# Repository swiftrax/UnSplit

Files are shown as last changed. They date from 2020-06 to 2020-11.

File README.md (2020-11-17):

# UnSplit
A Kyria layout with some of the thumb keys removed. It is non split and powered by an ATMega32u4-AU. Featuring an exposed component layout with diodes in a bank.

## PCB Renders
Top Full Ground Plane
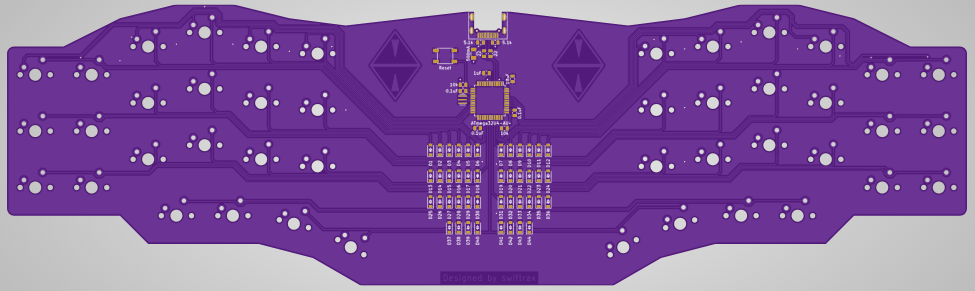
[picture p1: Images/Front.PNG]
Front Full Ground Plane

Bottom Full Ground Plane
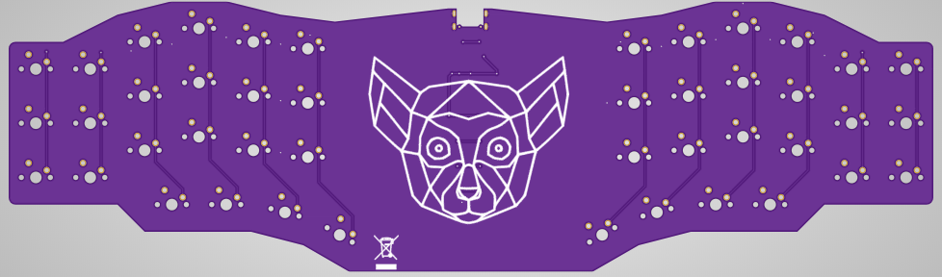
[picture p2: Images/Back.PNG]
Back Full Ground Plane

Top Partial Ground Plane
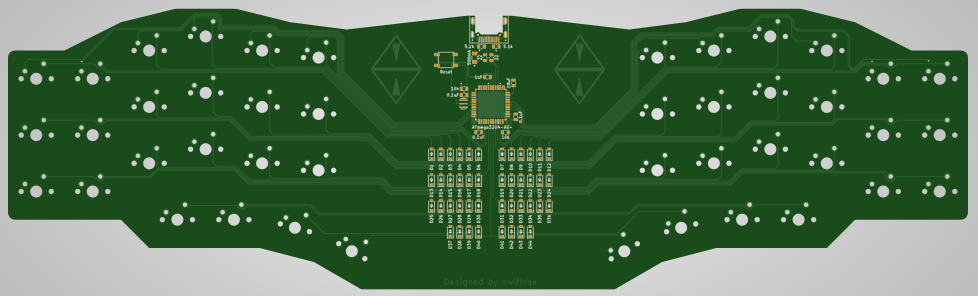
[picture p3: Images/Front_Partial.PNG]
Front Partial Ground Plane

Bottom Partial Ground Plane
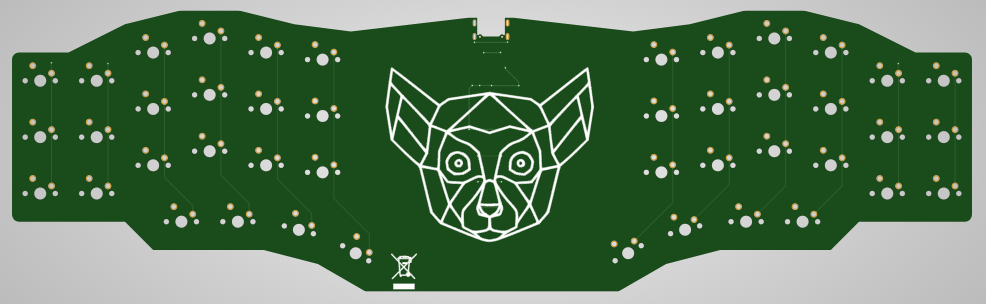
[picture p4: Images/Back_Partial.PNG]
Back Partial Ground Plane

*Open with KiCad nightly*

## Bill of Materials
* [ATMega32u4-AU x 1](https://lcsc.com/product-detail/ATMEL-AVR_Microchip-Tech-ATMEGA32U4-AU_C44854.html)
* [16MHz Resonator x 1](https://lcsc.com/product-detail/Others_Murata-Electronics-CSTNE16M0V530000R0_C341521.html)
* [22 Ohm Resistor x 2](https://lcsc.com/product-detail/Chip-Resistor-Surface-Mount_TyoHM-RMC0805221-N_C325772.html)
* [5.1k Ohm Resistor x 2](https://lcsc.com/product-detail/Chip-Resistor-Surface-Mount_TyoHM-RMC08055-1K1-N_C269748.html)
* [10k Ohm Resistor x 2](https://lcsc.com/product-detail/Chip-Resistor-Surface-Mount_TyoHM-RMC080510K1-N_C269742.html)
* [100nF Capactior x 3](https://lcsc.com/product-detail/Multilayer-Ceramic-Capacitors-MLCC-SMD-SMT_Walsin-Tech-Corp-0805B104J500CT_C314285.html)
* [1uF Capactior x 1](https://lcsc.com/product-detail/Multilayer-Ceramic-Capacitors-MLCC-SMD-SMT_FH-Guangdong-Fenghua-Advanced-Tech-0805B105K500NT_C215803.html)
* [10uF Capactior x 1](https://lcsc.com/product-detail/Multilayer-Ceramic-Capacitors-MLCC-SMD-SMT_SAMSUNG_CL10A106MA8NRNC_10uF-106-20-25V_C96446.html)
* [500mA Polyfuse x 1](https://lcsc.com/product-detail/Surface-Mount-Fuses_0-25A-16V-Self-healing-fuse_C70068.html)
* [Reset Switch x 1](https://lcsc.com/product-detail/Tactile-Switches_C-K_RS-187R05A2-DSMTRT_C-K-RS-187R05A2-DSMTRT_C221929.html)
* [Type C Port x 1](https://lcsc.com/product-detail/USB-Type-C_Korean-Hroparts-Elec-TYPE-C-31-M-14_C223907.html)
* [Diodes x 44](https://lcsc.com/product-detail/Diodes-General-Purpose_MDD-Microdiode-Electronics-SM4007PL_C64898.html)

*Capactiors and Resistors are 0805 Package size*

## License

This repository is under the [GNU GPL V2 license](https://github.com/swiftrax/UnSplit/blob/master/LICENSE). If you plan to sell these pcbs, make sure to read it.

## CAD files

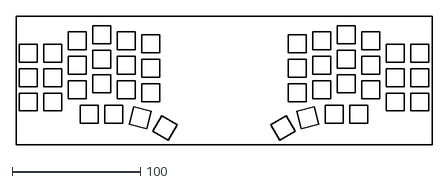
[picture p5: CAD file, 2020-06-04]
Plate/Plate.dxf
323.8 x 99.9

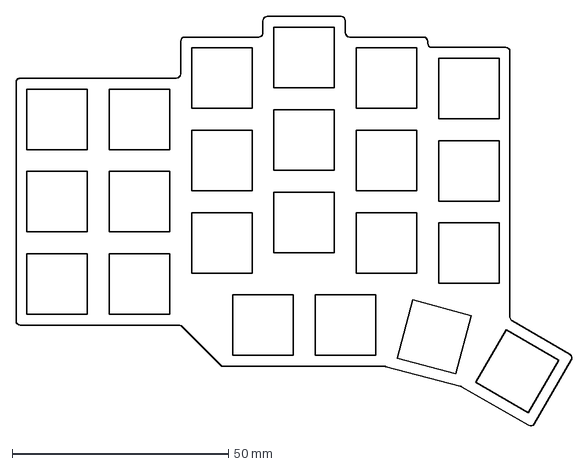
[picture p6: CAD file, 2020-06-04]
Plate/1Plate.dxf
128.6 x 94.9 mm

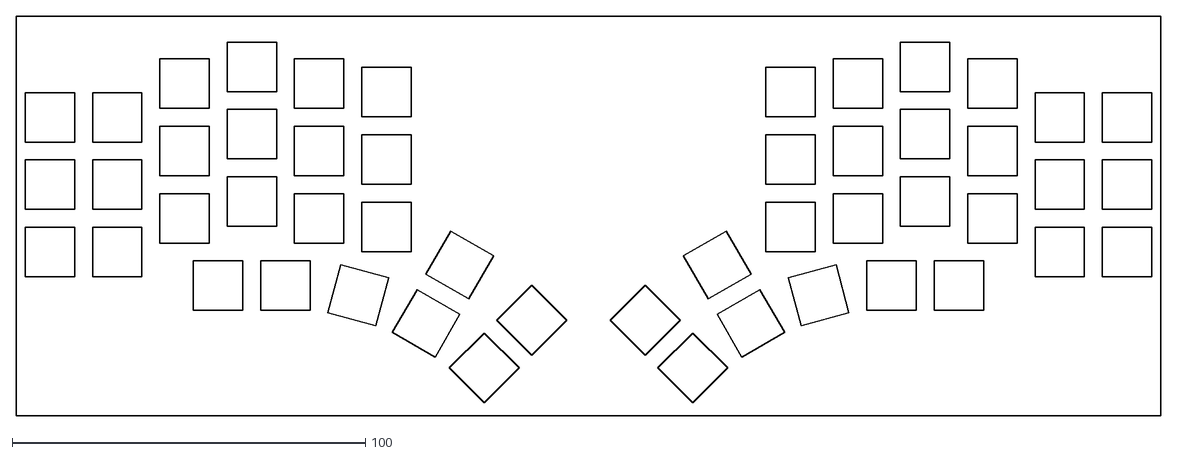
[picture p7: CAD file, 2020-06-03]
Plate/SwitchLayout.dxf
323.8 x 113.0

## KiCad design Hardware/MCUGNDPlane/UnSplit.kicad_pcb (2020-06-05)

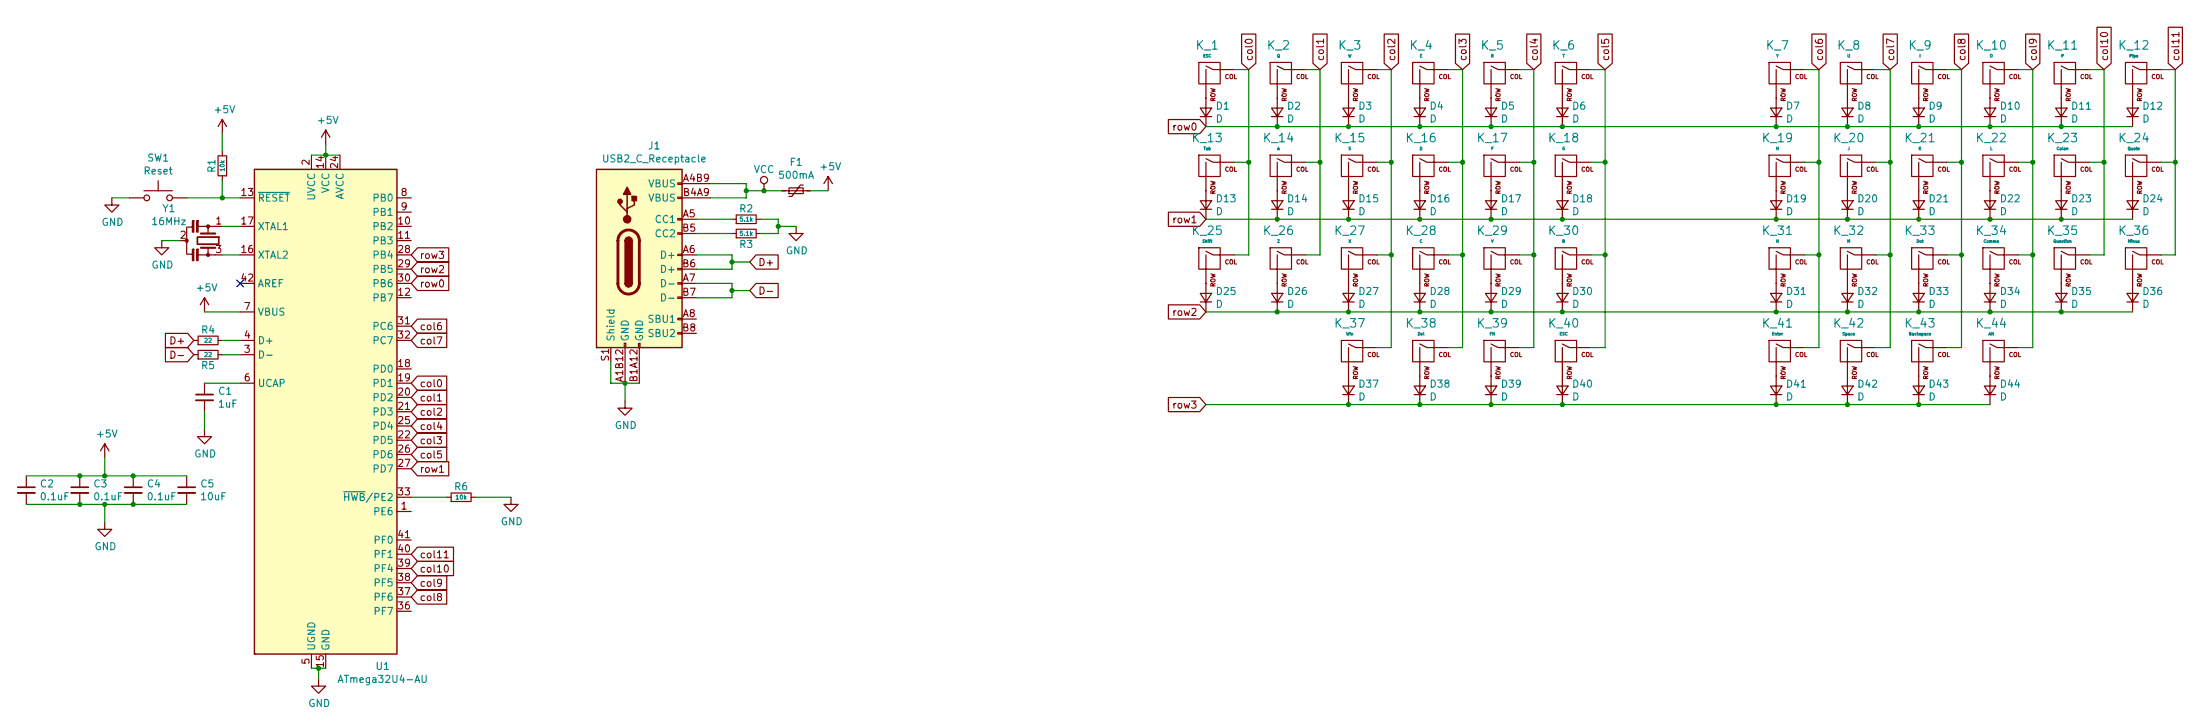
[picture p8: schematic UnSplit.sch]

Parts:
C1: 1uF; C_0805_2012Metric
C2, C3, C4: 0.1uF; C_0805_2012Metric
C5: 10uF; C_0805_2012Metric
D1, D2, D3, D4, D5, D6, D7, D8, D9, D10, D11, D12, D13, D14, D15, D16, D17, D18, D19, D20, D21, D22, D23, D24, D25, D26, D27, D28, D29, D30, D31, D32, D33, D34, D35, D36, D37, D38, D39, D40, D41, D42, D43, D44: D; D_SOD-123
F1: 500mA; Fuse_1206_3216Metric
J1: USB2_C_Receptacle; Mid_Mount-USB_C_HandSoldering
K_1, K_40: ESC; MXOnly-1U-NoLED
K_2: Q; MXOnly-1U-NoLED
K_3: W; MXOnly-1U-NoLED
K_4: E; MXOnly-1U-NoLED
K_5: R; MXOnly-1U-NoLED
K_6: T; MXOnly-1U-NoLED
K_7: Y; MXOnly-1U-NoLED
K_8: U; MXOnly-1U-NoLED
K_9: I; MXOnly-1U-NoLED
K_10: O; MXOnly-1U-NoLED
K_11: P; MXOnly-1U-NoLED
K_12: Pipe; MXOnly-1U-NoLED
K_13: Tab; MXOnly-1U-NoLED
K_14: A; MXOnly-1U-NoLED
K_15: S; MXOnly-1U-NoLED
K_16: D; MXOnly-1U-NoLED
K_17: F; MXOnly-1U-NoLED
K_18: G; MXOnly-1U-NoLED
K_19: H; MXOnly-1U-NoLED
K_20: J; MXOnly-1U-NoLED
K_21: K; MXOnly-1U-NoLED
K_22: L; MXOnly-1U-NoLED
K_23: Colon; MXOnly-1U-NoLED
K_24: Quote; MXOnly-1U-NoLED
K_25: Shift; MXOnly-1U-NoLED
K_26: Z; MXOnly-1U-NoLED
K_27: X; MXOnly-1U-NoLED
K_28: C; MXOnly-1U-NoLED
K_29: V; MXOnly-1U-NoLED
K_30: B; MXOnly-1U-NoLED
K_31: N; MXOnly-1U-NoLED
K_32: M; MXOnly-1U-NoLED
K_33: Dot; MXOnly-1U-NoLED
K_34: Comma; MXOnly-1U-NoLED
K_35: Question; MXOnly-1U-NoLED
K_36: Minus; MXOnly-1U-NoLED
K_37: Win; MXOnly-1U-NoLED
K_38: Del; MXOnly-1U-NoLED
K_39: FN; MXOnly-1U-NoLED
K_41: Enter; MXOnly-1U-NoLED
K_42: Space; MXOnly-1U-NoLED
K_43: Backspace; MXOnly-1U-NoLED
K_44: Alt; MXOnly-1U-NoLED
R1, R6: 10k; R_0805_2012Metric
R2, R3: 5.1k; R_0805_2012Metric
R4, R5: 22; R_0805_2012Metric
SW1: Reset; SKQG-1155865
U1: ATmega32U4-AU; TQFP-44_10x10mm_P0.8mm
Y1: 16MHz; Resonator_SMD_muRata_CSTxExxV-3Pin_3.0x1.1mm_HandSoldering_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

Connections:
+5V: C2.1, C3.1, C4.1, C5.1, F1.2, R1.2, U1.2 (UVCC), U1.7 (VBUS), U1.14 (VCC), U1.24 (AVCC), U1.34 (VCC), U1.44 (AVCC)
D+: J1.A6 (D+), J1.B6 (D+), R4.1
D-: J1.A7 (D-), J1.B7 (D-), R5.1
GND: C1.2, C2.2, C3.2, C4.2, C5.2, J1.A1B12 (GND), J1.B1A12 (GND), J1.S1 (Shield), R2.2, R3.2, R6.2, SW1.1, U1.5 (UGND), U1.15 (GND), U1.23 (GND), U1.35 (GND), U1.43 (GND), Y1.2
unnamed: C1.1, U1.6 (UCAP)
unnamed: D1.2 (A), K_1.2 (ROW)
unnamed: D2.2 (A), K_2.2 (ROW)
unnamed: D3.2 (A), K_3.2 (ROW)
unnamed: D4.2 (A), K_4.2 (ROW)
unnamed: D5.2 (A), K_5.2 (ROW)
unnamed: D6.2 (A), K_6.2 (ROW)
unnamed: D7.2 (A), K_7.2 (ROW)
unnamed: D8.2 (A), K_8.2 (ROW)
unnamed: D9.2 (A), K_9.2 (ROW)
unnamed: D10.2 (A), K_10.2 (ROW)
unnamed: D11.2 (A), K_11.2 (ROW)
unnamed: D12.2 (A), K_12.2 (ROW)
unnamed: D13.2 (A), K_13.2 (ROW)
unnamed: D14.2 (A), K_14.2 (ROW)
unnamed: D15.2 (A), K_15.2 (ROW)
unnamed: D16.2 (A), K_16.2 (ROW)
unnamed: D17.2 (A), K_17.2 (ROW)
unnamed: D18.2 (A), K_18.2 (ROW)
unnamed: D19.2 (A), K_19.2 (ROW)
unnamed: D20.2 (A), K_20.2 (ROW)
unnamed: D21.2 (A), K_21.2 (ROW)
unnamed: D22.2 (A), K_22.2 (ROW)
unnamed: D23.2 (A), K_23.2 (ROW)
unnamed: D24.2 (A), K_24.2 (ROW)
unnamed: D25.2 (A), K_25.2 (ROW)
unnamed: D26.2 (A), K_26.2 (ROW)
unnamed: D27.2 (A), K_27.2 (ROW)
unnamed: D28.2 (A), K_28.2 (ROW)
unnamed: D29.2 (A), K_29.2 (ROW)
unnamed: D30.2 (A), K_30.2 (ROW)
unnamed: D31.2 (A), K_31.2 (ROW)
unnamed: D32.2 (A), K_32.2 (ROW)
unnamed: D33.2 (A), K_33.2 (ROW)
unnamed: D34.2 (A), K_34.2 (ROW)
unnamed: D35.2 (A), K_35.2 (ROW)
unnamed: D36.2 (A), K_36.2 (ROW)
unnamed: D37.2 (A), K_37.2 (ROW)
unnamed: D38.2 (A), K_38.2 (ROW)
unnamed: D39.2 (A), K_39.2 (ROW)
unnamed: D40.2 (A), K_40.2 (ROW)
unnamed: D41.2 (A), K_41.2 (ROW)
unnamed: D42.2 (A), K_42.2 (ROW)
unnamed: D43.2 (A), K_43.2 (ROW)
unnamed: D44.2 (A), K_44.2 (ROW)
unnamed: J1.A5 (CC1), R2.1
unnamed: J1.B5 (CC2), R3.1
unnamed: R1.1, SW1.2, U1.13 (~RESET)
unnamed: R4.2, U1.4 (D+)
unnamed: R5.2, U1.3 (D-)
unnamed: R6.1, U1.33 (~HWB~/PE2)
unnamed: U1.16 (XTAL2), Y1.3
unnamed: U1.17 (XTAL1), Y1.1
VCC: F1.1, J1.A4B9 (VBUS), J1.B4A9 (VBUS)
col0: K_1.1 (COL), K_13.1 (COL), K_25.1 (COL), U1.19 (PD1)
col1: K_2.1 (COL), K_14.1 (COL), K_26.1 (COL), U1.20 (PD2)
col2: K_3.1 (COL), K_15.1 (COL), K_27.1 (COL), K_37.1 (COL), U1.21 (PD3)
col3: K_4.1 (COL), K_16.1 (COL), K_28.1 (COL), K_38.1 (COL), U1.22 (PD5)
col4: K_5.1 (COL), K_17.1 (COL), K_29.1 (COL), K_39.1 (COL), U1.25 (PD4)
col5: K_6.1 (COL), K_18.1 (COL), K_30.1 (COL), K_40.1 (COL), U1.26 (PD6)
col6: K_7.1 (COL), K_19.1 (COL), K_31.1 (COL), K_41.1 (COL), U1.31 (PC6)
col7: K_8.1 (COL), K_20.1 (COL), K_32.1 (COL), K_42.1 (COL), U1.32 (PC7)
col8: K_9.1 (COL), K_21.1 (COL), K_33.1 (COL), K_43.1 (COL), U1.37 (PF6)
col9: K_10.1 (COL), K_22.1 (COL), K_34.1 (COL), K_44.1 (COL), U1.38 (PF5)
col10: K_11.1 (COL), K_23.1 (COL), K_35.1 (COL), U1.39 (PF4)
col11: K_12.1 (COL), K_24.1 (COL), K_36.1 (COL), U1.40 (PF1)
row0: D1.1 (K), D2.1 (K), D3.1 (K), D4.1 (K), D5.1 (K), D6.1 (K), D7.1 (K), D8.1 (K), D9.1 (K), D10.1 (K), D11.1 (K), D12.1 (K), U1.30 (PB6)
row1: D13.1 (K), D14.1 (K), D15.1 (K), D16.1 (K), D17.1 (K), D18.1 (K), D19.1 (K), D20.1 (K), D21.1 (K), D22.1 (K), D23.1 (K), D24.1 (K), U1.27 (PD7)
row2: D25.1 (K), D26.1 (K), D27.1 (K), D28.1 (K), D29.1 (K), D30.1 (K), D31.1 (K), D32.1 (K), D33.1 (K), D34.1 (K), D35.1 (K), D36.1 (K), U1.29 (PB5)
row3: D37.1 (K), D38.1 (K), D39.1 (K), D40.1 (K), D41.1 (K), D42.1 (K), D43.1 (K), D44.1 (K), U1.28 (PB4)

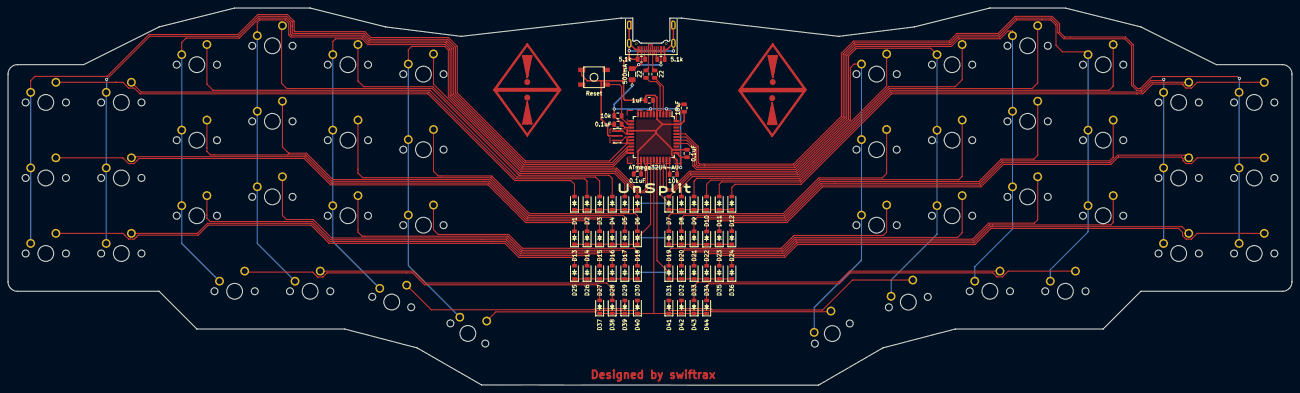
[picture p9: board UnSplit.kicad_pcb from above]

Board: 2 copper layers, 323.9 x 95.1 mm, 104 parts (0 on the bottom side), 74 nets.

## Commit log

2020-06-03 Route Diodes
    [NonSplitKyria.kicad_pcb, NonSplitKyria.sch]
2020-06-04 Route MCU rows + cols
    [NonSplitKyria.kicad_pcb, NonSplitKyria.sch]
2020-06-04 Add Silkscreen art
    [NonSplitKyria.kicad_pcb]
2020-06-04 Add Gerbers
    [NonSplitKyria-B_Cu.gbr, NonSplitKyria-B_Mask.gbr, NonSplitKyria-B_SilkS.gbr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]
2020-06-04 Redo Gerbers
    [NonSplitKyria-B_Cu.gbr, NonSplitKyria-B_Mask.gbr, NonSplitKyria-B_SilkS.gbr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]
2020-06-04 Add PCB Renders
2020-06-04 Green PCB render
2020-06-04 Add plates
    [1Plate.dxf, Plate.dxf]
2020-06-05 Organize Files
    [NonSplitKyria-B_Cu.gbr, NonSplitKyria-B_Mask.gbr, NonSplitKyria-B_SilkS.gbr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]
2020-06-05 Add Purple PCB Renders
2020-06-05 Add Minimal GND plane images
2020-07-09 Add BOM
